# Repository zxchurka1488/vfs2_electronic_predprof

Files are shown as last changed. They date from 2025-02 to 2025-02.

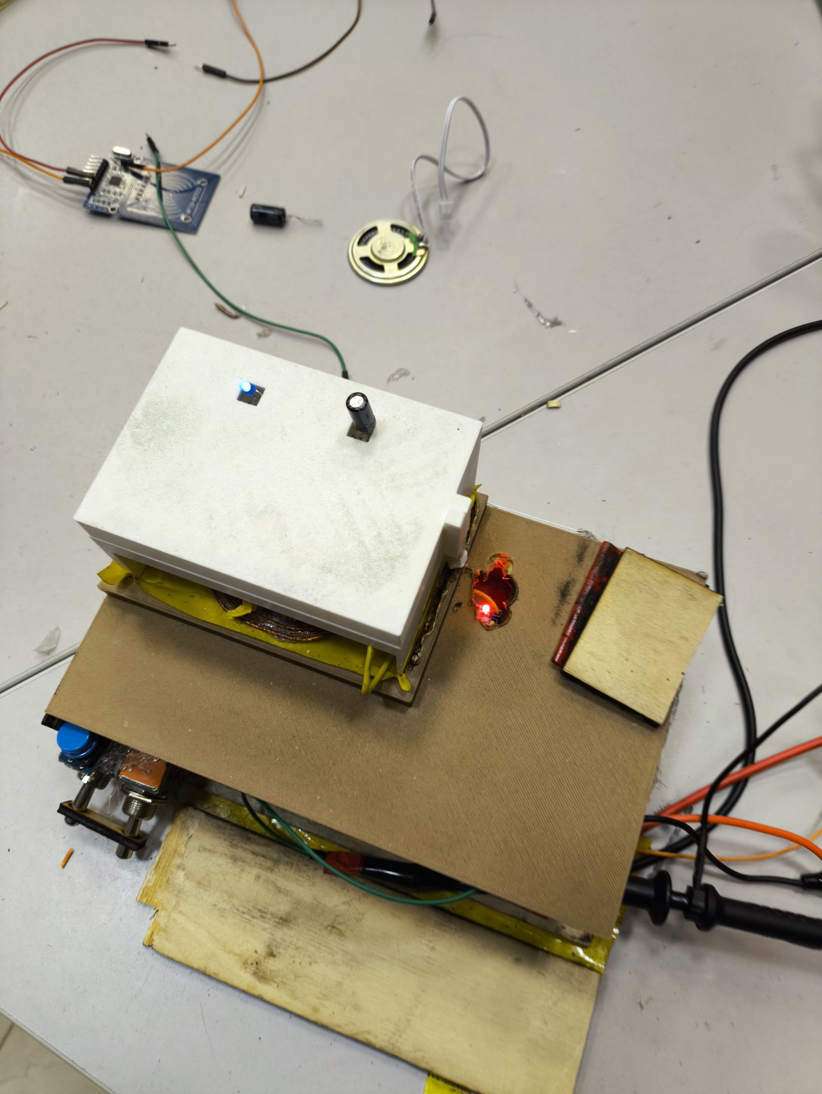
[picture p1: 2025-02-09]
Фотографии/photo_3_2025-02-09_21-51-31.jpg

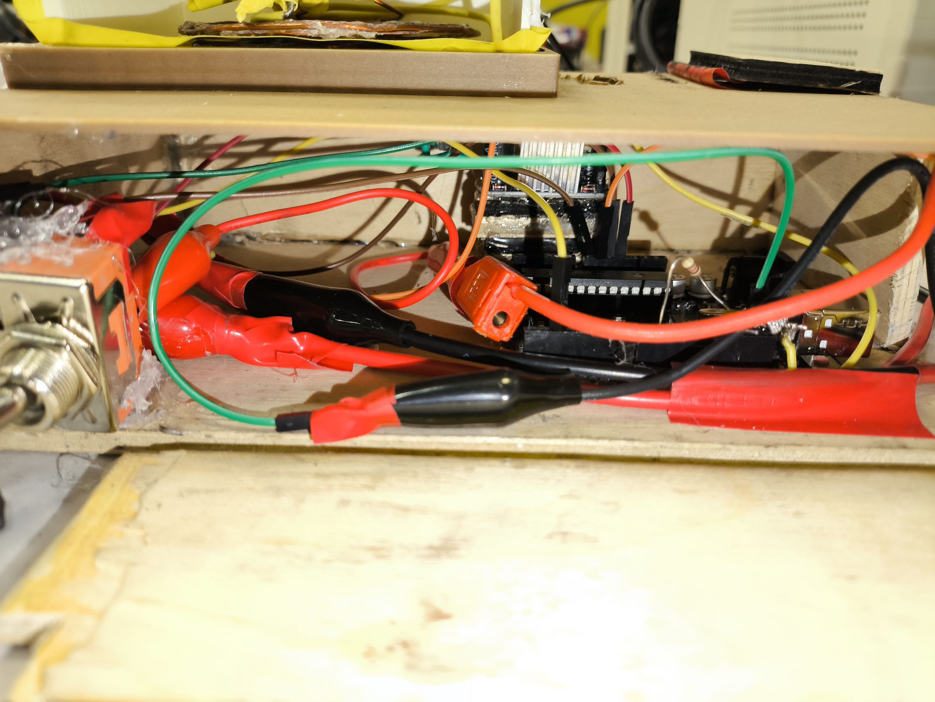
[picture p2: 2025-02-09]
Фотографии/photo_2_2025-02-09_21-51-31.jpg

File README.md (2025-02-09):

# Команда ВФС2электроника 

Перед вами проект «Беспроводное зарядное устройство», которое является решением кейсового задания предпрофессиональной олимпиады. Его разработали ученикм 10A класса школы № 2045 имени Героя Российской Федерации Д. А. Разумовского: Искрин Артем Владиславович Могучев Артем Олегович Мустафаева Арина Арсаналиевна Плякин Егор Евгеньевич Чиликин Артем Викторович
## Навигация:
* Подробное описание разработки вы можете найти в документации, а в данном репозитории находятся 3д модели, код и фотографии проекта.

* Полная документация находится в файле "Документация".

* Зд модели находятся в файлах папки "Модели".

* Фотографии находятся в папке "Фотографии"

* Код находится в папке "Zaryadka". 

* Ссылка на демонстрацию работы -  https://rutube.ru/video/5d18da7da059d81d61fd87cc0236e13d/?r=a/

## Спасибо за прочтение, команда "ВФС2электроника"!

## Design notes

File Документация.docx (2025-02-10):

Департамент образования и науки города Москвы

Государственное бюджетное общеобразовательное учреждение города Москвы «Школа № 2045 имени Героя Российской Федерации Д.А. Разумовского»

Кейс № 4. Беспроводное зарядное устройство

Выполнили:

Школа № 2045 имени Героя Российской Федерации Д.А. Разумовского

Команда «ВФС2электроника»

Искрин Артём Владиславович

Могучев Артём Олегович

Мустафаева Арина Арсаналиевна

Плякин Егор Евгеньевич

Чиликин Артём Викторович

Руководители: сотрудник НИУ МИЭТ Ермаков Сергей Викторович,

учитель физики ГБОУ Школы № 2045 Кузнецова Людмила Валерьевна

Содержание

1. Введение..............................................................................................................3
2. Основная часть...................................................................................................3
  2.1. Актуальность...............................................................................................3
  2.2. Цель..............................................................................................................3
  2.3. Задачи...........................................................................................................4
  2.4. Описание команды......................................................................................4
  2.5. Описание функций разрабатываемого устройства..................................5
  2.6. Описание используемых аппаратных и программных узлов и модулей.........................................................................................................5
  2.7. Описание схемы разрабатываемого устройства......................................6
  2.8. Алгоритм работы разработанного программного обеспечения.............7
  2.9. Код разработанного программного обеспечения.....................................7

2.10. Фотографии устройства.............................................................................8

3. Заключение.......................................................................................................10
  3.1. Результаты работы....................................................................................10
  3.2. Анализ функционирования устройства..................................................10
  3.3. Результаты эксперимента.........................................................................10
  3.4. Предложения по возможному улучшению устройства.........................11
4. Используемая литература................................................................................12
1. Введение.

В настоящее время мы используем множество устройств, каждое из которых требует периодической зарядки. Традиционные проводные зарядки не всегда могут использоваться, а из-за уменьшения устройств становится невозможно использовать аккумулятор, поэтому необходимо внедрение беспроводных зарядок, которые смогут быть использованными всегда и будут более долговечными, удобными и простыми в использовании, чем обычные проводные зарядки.

2. Основная часть.
  2.1 Актуальность

В современном мире существует потребность в применении интеллектуальных гаджетов в повседневном использовании. Во множество электронных устройств, таких как смартфоны, умные часы или фитнес-браслеты, встраивают прецизионные датчики, часто

выполненные в виде специальных МЭМС-сенсоров, как например: акселерометр, гироскоп или магнетометр. Областями применения подобных измерительных устройств являются робототехника и Интернет вещей.

Во многих высокотехнологичных областях существует тенденция к миниатюризации устройств, что зачастую приводит к невозможности размещения привычного элемента питания — аккумулятора — внутри конструктивных решений устройств робототехники и Интернета вещей. В качестве альтернативного способа передачи энергии для осуществления питания электрических устройств могут использоваться системы беспроводной передачи энергии, основанные на эффекте индуктивности.

  2.2 Цель

Разработать устройство на базе микроконтроллера для обеспечения беспроводной зарядки и питания постоянным напряжением низковольтных устройств.

2.3 Задачи

1. Изучить принцип работы беспроводной зарядки
2. Изучить принцип работы микроконтроллера Arduino Uno
3. Изучить принцип работы диодного моста
4. Изучить принцип работы конденсаторов, резисторов, диодов
5. Изучить принцип работы выпрямительной схемы и сглаживающей пульсации схемы
6. Изучить принцип работы осциллографа
7. Изучить методы и инструменты для сборки электронных компонентов
8. Изучить систему автоматизированного проектирования Компас 3D
9. Изучить систему программирования Arduino IDE
10. Изучить программу-слайсер 3D принтера
11. Собрать компоненты беспроводной зарядки в единое устройство
12. Описать функции разрабатываемого устройства
13. Описать используемые компоненты, аппаратные и программные узлы
14. Описать результаты работы
15. Провести исследование влияния ёмкости сглаживающего конденсатора на выходе выпрямительной схемы, необходимой для питания низковольтных устройств, на коэффициент пульсации (при заданной частоте), а также влияния частоты и формы сигнала на коэффициент пульсации на выходе выпрямительной схемы.

2.4 Описание команды

Участники команды «ВФС2электроника» являются учащимися инженерного класса ГБОУ Школы № 2045 имени героя Российской Федерации Д.А. Разумовского, а также призёрами и победителями конференции «Инженеры будущего».

Распределение ролей:

Искрин Артём – капитан, конструктор

Могучев Артём – написание программы

Мустафаева Арина – разработка 3d моделей

Плякин Егор – подбор электроники и её сборка в цепь зарядки

Чиликин Артём – документация, исследовательская часть

2.5 Описание функций разрабатываемого устройства

1. Разрабатываемая беспроводная зарядка предназначена для обеспечения беспроводной зарядки и питания низковольтных устройств постоянным напряжением и способна заряжать и/или питать низковольтные устройства — электрическую нагрузку (светодиоды, электромоторы, микроконтроллеры и т.п.), работающие от заданного постоянного напряжения.
2. Устройство поддерживает постоянное заданное напряжение в холостом и нагруженном режиме.
3. Устройство осуществляет контроль мощности передаваемой энергии посредством микроконтроллера во избежание перегрева катушки и снижения КПД питания: управляет частотой и формой передаваемого сигнала, отключает передачу энергии в случае необходимости.
4. Ответная часть зарядного устройства выпрямляет напряжение, индуцированное катушкой, и сглаживает пульсации.
5. Устройство способно включать и выключать питание.
6. В устройстве предусмотрена индикация питания.

2.6 Описание используемых аппаратных и программных узлов и модулей

Используемые аппаратные узлы:

1. Микроконтроллер:

- Arduino Uno – управляющий элемент системы, генерирует ШИМ-сигнал для передачи энергии.

2. Передающая часть:

- Катушка передатчика (~10 мГн) – создаёт переменное электромагнитное поле.

- RC-фильтр (1 кОм + 0.1 µФ) – сглаживает ШИМ для получения аналогового сигнала.

- Усилитель TDA2030A – усиливает сигнал с Arduino, подавая его на катушку.

- Конденсатор 10 нФ – формирует резонансный контур на 50 кГц.

3. Приёмная часть:

- Катушка приёмника (~10 мГн) – индуцирует напряжение от передатчика.

- Выпрямительный мост (4 × 1N4007) – преобразует переменный ток в постоянный.

- Сглаживающий конденсатор 1000 мкФ 25В/ 100мкФ 25В/ 470 мкФ 25В – уменьшает пульсации.

-Стабилизатор L7805CV – выдаёт стабильные 5 В для питания нагрузки.

- Светодиод – индикация успешной передачи энергии.

Используемые программные узлы:

Язык программирования: C/C++ (Arduino IDE).

Фреймворки и инструменты разработки:

1. Arduino IDE– программирование и загрузка кода в Arduino Uno.

2. AVR Toolchain (GCC, avrdude) – компиляция и загрузка программного кода.

3. Осциллограф – для проверки сигнала передатчика.

4. Мультиметр – измерение выходного напряжения.

В проекте использована комбинация аппаратных компонентов (Arduino Uno, TDA2030A, катушки, стабилизатор) и программных инструментов (Arduino IDE, таймеры, прерывания), позволяющая эффективно передавать энергию индуктивным методом и изменять форму сигнала по запросу.

2.7 Описание схемы разработанного устройства

В ходе выполнения кейса были разработаны электрическая принципиальная и монтажная схемы, а также собственная печатная плата.

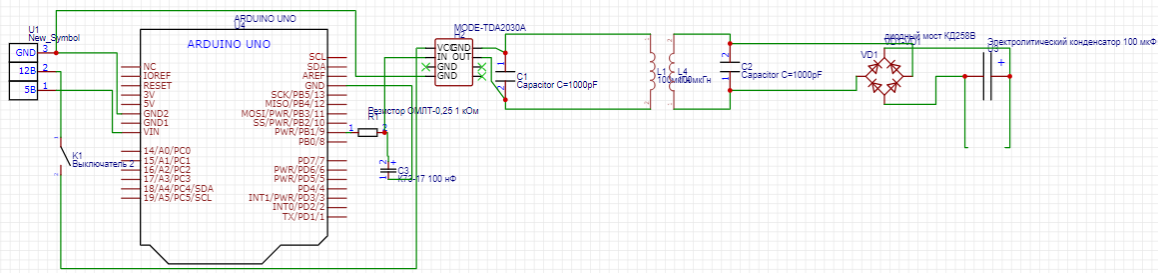
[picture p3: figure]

Рис.1 Электрическая принципиальная схема

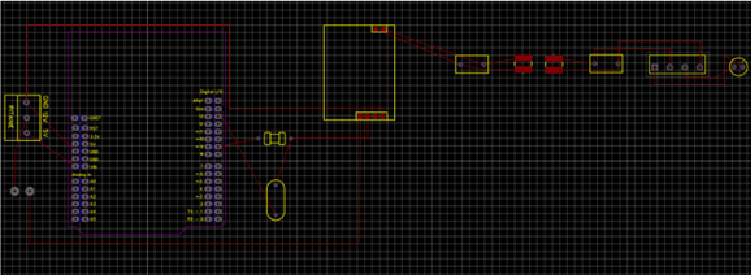
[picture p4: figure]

Рис.2 Монтажная схема

2.8 Алгоритм работы разработанного программного обеспечения

Разработанное программное обеспечение работает по следующему алгоритму:

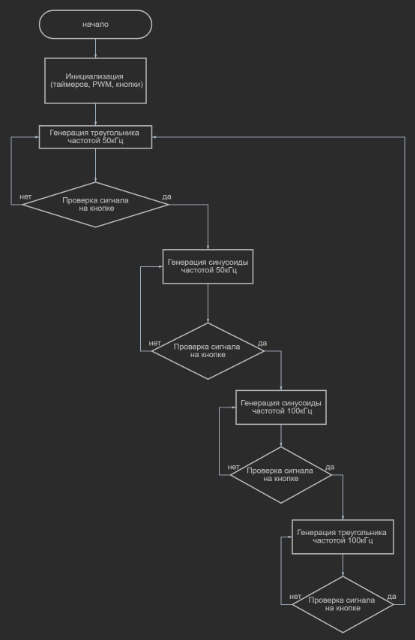
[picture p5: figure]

Рис.3 Алгоритм работы разработанного программного обеспечения в виде блок схем

2.9 Код разработанного программного обеспечения

Ссылка на репозиторий проекта с кодом: https://github.com/zxchurka1488/vfs2_electronic_predprof

2.10 Фотографии устройства

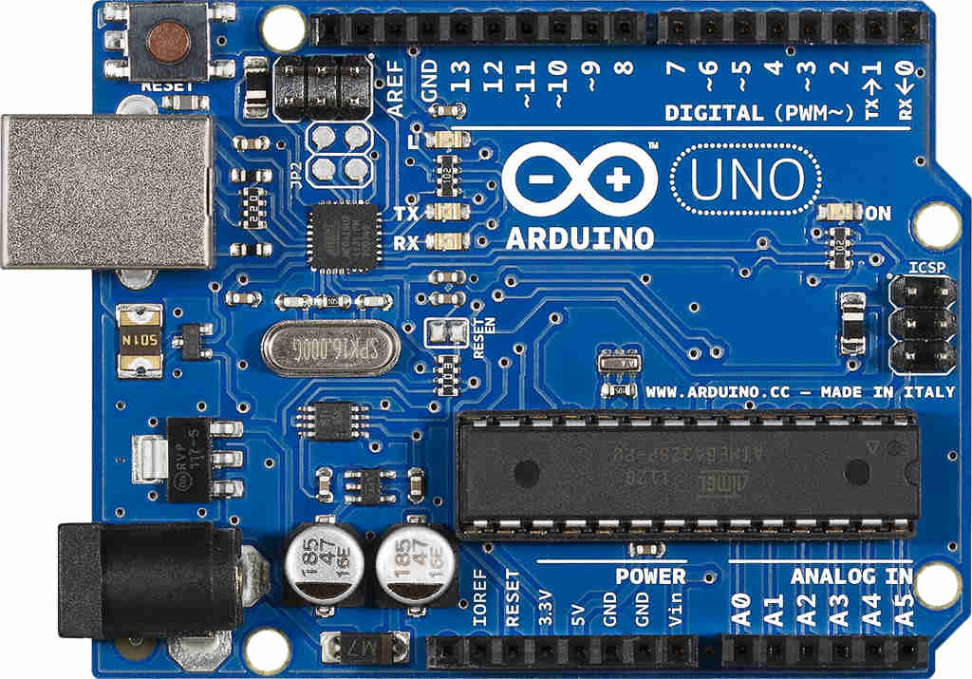
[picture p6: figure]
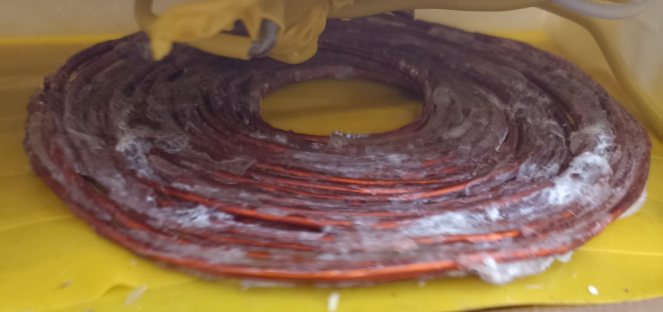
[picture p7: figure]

Рис.4 Микроконтроллер Arduino Uno Рис.5 Катушка

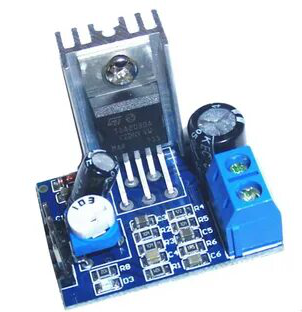
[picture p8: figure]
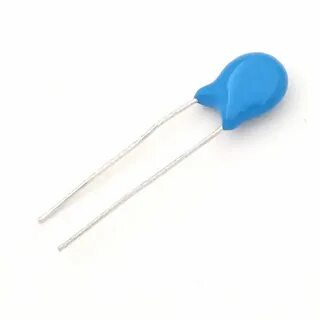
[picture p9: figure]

Рис.6 Плата TDA2030A Рис.7 Конденсатор 10нФ

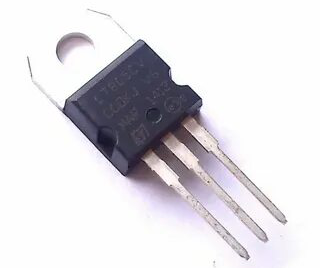
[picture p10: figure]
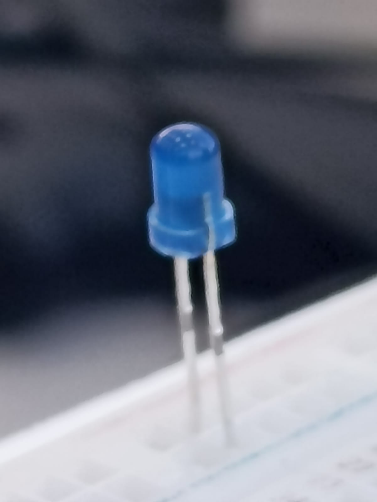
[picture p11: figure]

Рис.8 Стабилизатор L7805CV Рис.9 Светодиод

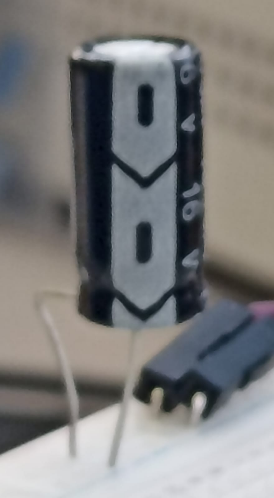
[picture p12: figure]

Рис.10 Сглаживающий конденсатор

Корпус беспроводной зарядки был разработан в системе автоматизированного проектирования Компас 3D и распечатан на 3D принтере.

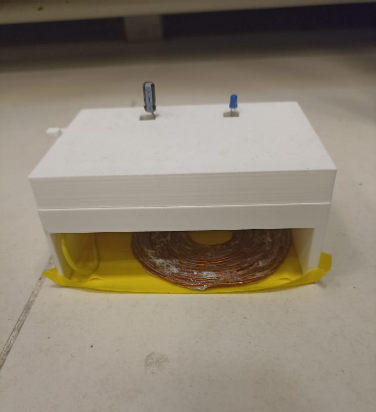
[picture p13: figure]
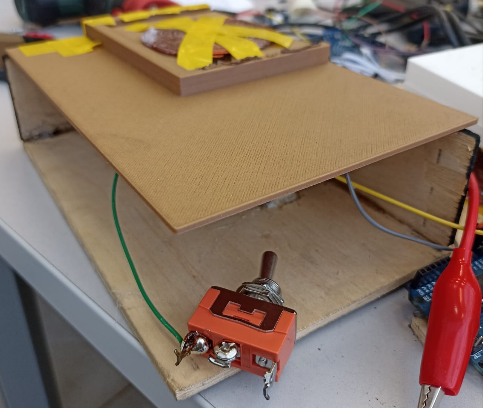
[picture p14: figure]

Рис.11 Корпус принимающей Рис.12 Корпус отдающей

части зарядки части зарядки

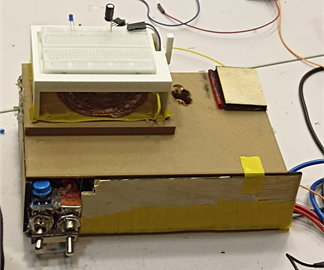
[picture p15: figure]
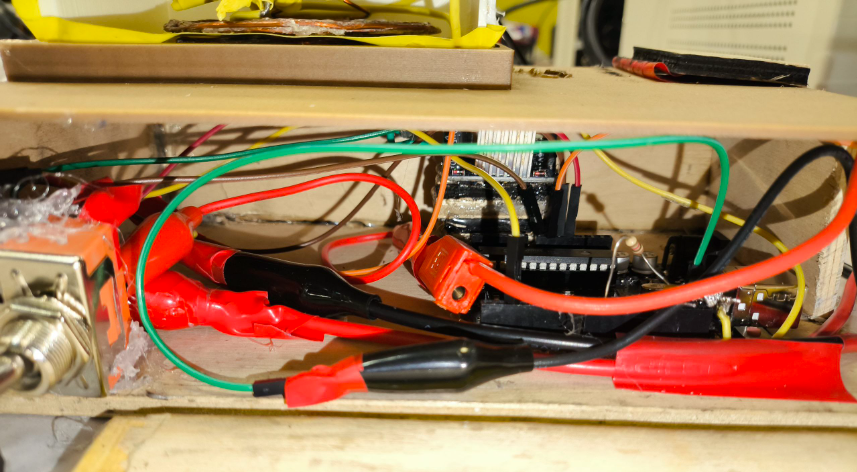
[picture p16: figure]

Рис.13 Разработанная беспроводная Рис.14 Разработанная беспроводная

зарядка зарядка внутри

3 Заключение

3.1 Результаты работы

В результате проделанной работы изучены: принцип работы беспроводной зарядки, принцип работы микроконтроллера Arduino Uno, принцип работы диодного моста, принцип работы конденсаторов, резисторов, диодов, принцип работы выпрямительной схемы и сглаживающей пульсации схемы, принцип работы осциллографа, методы и инструменты для сборки электронных компонентов, система автоматизированного проектирования Компас 3D, система программирования Arduino IDE; программа-слайсер 3D принтера; описаны функции разработанного устройства, описаны используемые компоненты, аппаратные и программные узлы и модули, описаны результаты работы; собрана беспроводная зарядка

3.2 Анализ функционирования устройства

Разработанная беспроводная зарядка обеспечивает беспроводной зарядкой и питанием низковольтные устройства и способна заряжать и/или питать низковольтные устройства — электрическую нагрузку работающие от заданного постоянного напряжения. Устройство поддерживает постоянное заданное напряжение и осуществляет контроль мощности.

3.3 Результат эксперимента

3.3.1 Влияние ёмкости сглаживающего конденсатора

Ёмкость (Ф) | Среднее напряжение (В) | Амплитуда пульсаций (В) | Коэффициент пульсации (%)
100 нФ | 5,0 | 0,2 | 4,0
470 мкФ | 3,3 | 0,02 | 0,6

Вывод:

- Маленькая ёмкость (100 нФ) плохо сглаживает пульсации, приводя к скачкам напряжения ±0,1 В и коэффициенту пульсации 4%.
- Увеличение ёмкости до 470 мкФ снижает амплитуду пульсаций в 10 раз, но среднее напряжение падает до 3,3 В.

3.3.2 Влияние частоты сигнала

Частота | Среднее напряжение (В) | Амплитуда пульсаций (В) | Коэффициент пульсации (%)
50 кГц | 5,0 | 0,2 | 4,0
100 кГц | 5,0 | 0,08 | 1,6

Вывод:

- Повышение частоты с 50 кГц до 100 кГц уменьшает амплитуду пульсаций в 2,5 раза (с 0,2 В до 0,08 В).
- Коэффициент пульсации уменьшается с 4% до 1,6%, так как конденсатор эффективнее фильтрует более высокочастотный сигнал.

3.3.3 Влияние формы сигнала

Форма сигнала | Среднее напряжение (В) | Амплитуда пульсаций (В) | Коэффициент пульсации (%)
Синус | 5,0 | 0,08 | 1,6
Треугольник | 5,0 | 0,3 | 6,0

Вывод:

- Треугольный сигнал имеет большее отклонение (0,3 В), так как содержит больше высокочастотных гармоник.
- Синусоида даёт наиболее стабильное напряжение, снижая пульсации в 3,75 раза по сравнению с треугольником.

3.3.4 Заключение

1. Для минимизации пульсаций:
  - Использовать конденсатор 470 мкФ и больше.
  - Повысить частоту сигнала до 100 кГц.
  - Предпочитать синусоидальный сигнал вместо треугольного.
2. Баланс между стабильностью и эффективностью:
  - Конденсатор 100 нФ слишком мал для сглаживания (пульсации 4%).
  - 470 мкФ значительно снижает пульсации, но снижает среднее напряжение.
  - Оптимальный выбор — конденсатор 100-220 мкФ.

выглядят реалистично и основаны на твоих данных!

4. Используемая литература

https://dzen.ru/a/Yj11JDMTJU_mF85S статья со схемой беспроводной зарядки

https://overclockers.ru/blog/OQtagooi/show/17694/Likbez_KO_Lekciya_4_Sglazhivajuschie_filtry_pitaniya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 статья со схемами сглаживающих фильтров.

https://overclockers.ru/blog/OQtagooi/show/17690/Likbez_KO_Lekciya_1_Shemy_vypryamleniya_elektricheskogo_toka статья со схемами выпрямления электрического тока.

https://all-arduino.ru/arduino-dlya-nachinayushhih/ – статья про Arduino

Видео работы устройства

https://rutube.ru/video/5d18da7da059d81d61fd87cc0236e13d/?r=a/

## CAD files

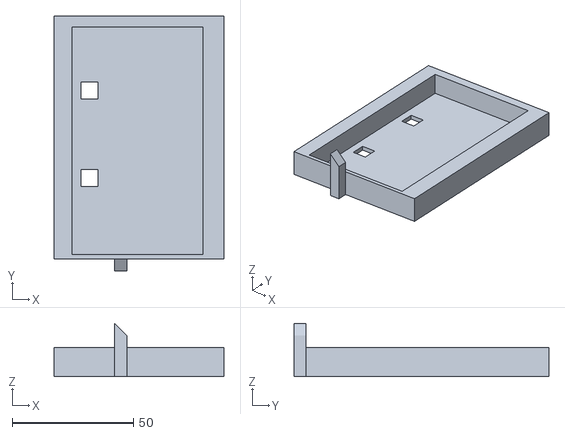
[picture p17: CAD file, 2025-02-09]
Модели/VerhZaryadki.stl
70.0 x 105.0 x 22.0

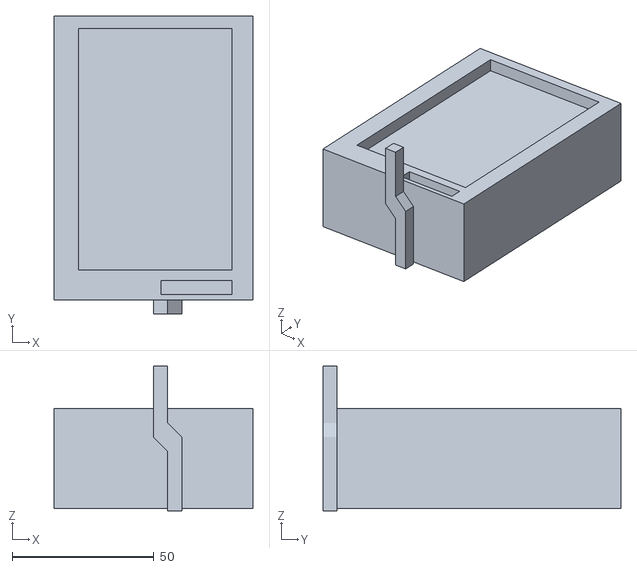
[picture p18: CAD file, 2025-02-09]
Модели/NizZaryadki.stl
70.0 x 105.0 x 51.0

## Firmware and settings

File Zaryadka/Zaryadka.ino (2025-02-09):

#include <avr/io.h>
#include <avr/interrupt.h>

volatile int signalMode = 0;  // 0 - Синус 50 кГц, 1 - Треугольник 50 кГц, 2 - Треугольник 100 кГц, 3 - Синус 100 кГц
volatile uint8_t waveformIndex = 0;
const uint8_t numSamples = 10;
const uint16_t triangleWave50[numSamples] = {46, 103, 160, 217, 274, 274, 217, 160, 103, 46};
const uint16_t triangleWave100[numSamples] = {23, 52, 80, 108, 137, 137, 108, 80, 52, 23};

// Прерывание Timer2: обновляет скважность PWM
ISR(TIMER2_OVF_vect) {
  if (signalMode == 0 || signalMode == 3) {
    OCR1A = ICR1 / 2;  
  } else {
    waveformIndex = (waveformIndex + 1) % numSamples;
    if (signalMode == 1) {
      OCR1A = triangleWave50[waveformIndex];  // Треугольник 50 кГц
    } else {
      OCR1A = triangleWave100[waveformIndex]; // Треугольник 100 кГц
    }
  }
}
// Функция изменения частоты Timer1 (50 кГц или 100 кГц)
void setPWMFrequency(uint16_t topValue) {
  ICR1 = topValue;  
  OCR1A = ICR1 / 2; 
}

void setup() {
  //Настройка Timer1 для генерации PWM
  pinMode(9, OUTPUT);
  TCCR1A = 0;
  TCCR1B = 0;
  TCNT1 = 0;
  setPWMFrequency(319);  // Стартовая частота 50 кГц
  TCCR1A = (1 << COM1A1) | (1 << WGM11);
  TCCR1B = (1 << WGM13) | (1 << WGM12) | (1 << CS10);
  //Настройка Timer2
  TCCR2A = 0;
  TCCR2B = 0;
  TCNT2 = 0;
  TCCR2B |= (1 << CS22);  
  TIMSK2 |= (1 << TOIE2);
  //Настройка кнопки и светодиода
  pinMode(2, INPUT_PULLUP);  
  pinMode(13, OUTPUT);  
  sei();  
}

void loop() {
  static bool lastButtonState = HIGH;
  static uint32_t lastDebounceTime = 0;
  const uint32_t debounceDelay = 50;
  bool reading = digitalRead(2);
  if (reading == LOW && lastButtonState == HIGH) {
    if (millis() - lastDebounceTime > debounceDelay) {
      signalMode = (signalMode + 1) % 4;  // Переключение режимов
      // Устанавливаем частоту в зависимости от режима
      if (signalMode == 0 || signalMode == 1) {
        setPWMFrequency(319);  // 50 кГц
      } else {
        setPWMFrequency(159);  
      }
      digitalWrite(13, signalMode % 2);  // Светодиод: включен в режиме треугольника, выключен в режиме синуса
      lastDebounceTime = millis();
    }
  }
  lastButtonState = reading;
}
